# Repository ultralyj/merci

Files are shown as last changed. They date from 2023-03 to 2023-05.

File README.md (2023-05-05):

# MERCI Project

Say Merci!!!

ultralyj的毕设，

looking for the magic of magnet,

say merci to graduate,

------------------------------

项目目前包含：

- [x] 嵌入式代码（基于stm32f4）
- [x] 硬件PCB（包含`F4V3`，`Finger`两款）

  F4V3是30mm试验型磁触觉电子皮肤

  Fringer是安装在AG-145夹爪上的传感器，MCU分体，FPC连接的微型磁触觉电子皮肤

- [x] 3D模型（包含F4V3的模具，压力计外壳，标定用的压头等）

- [x] 传感器网络（目前使用MLP搭建）
- [x] 标定一体化界面（Qt构建，统一管理标定测试台，压力计与电子皮肤，实现电子皮肤标定无人化）
- [x] 电子皮肤上位机（Electrion+React+AntD构建，简明，优美的图形化GUI，包含安装包）
- [x] Comsol磁场仿真模型（对磁化过程进行了简单仿真）

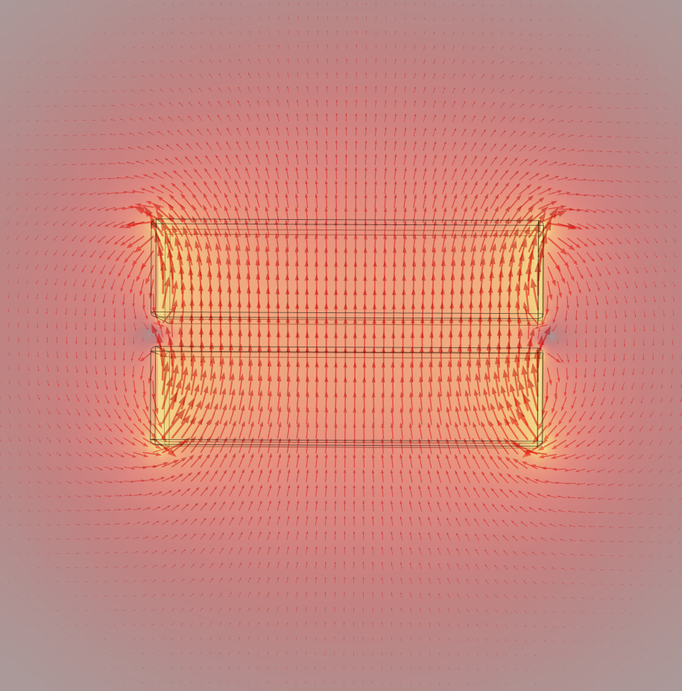
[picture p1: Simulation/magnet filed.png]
magnet filed
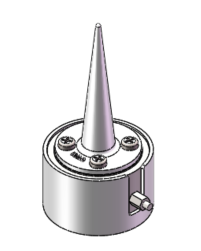
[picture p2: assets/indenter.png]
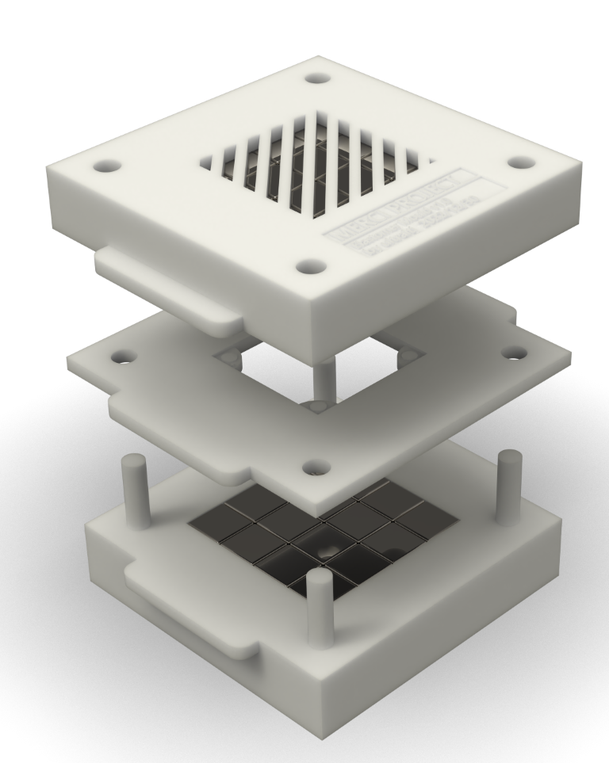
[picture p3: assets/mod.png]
mod
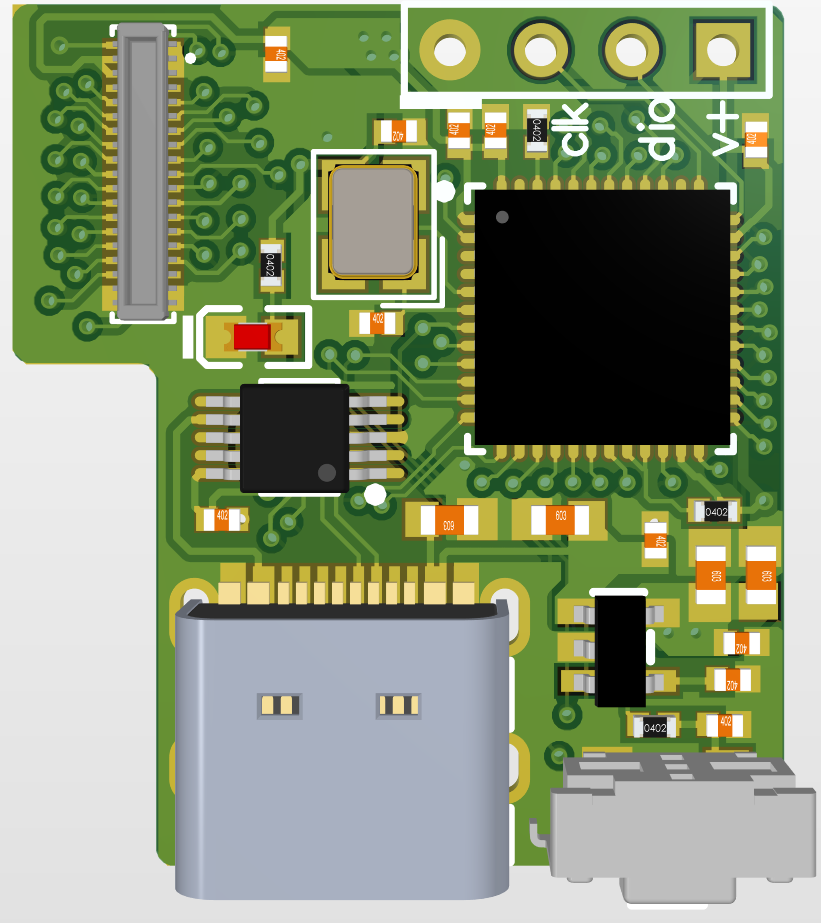
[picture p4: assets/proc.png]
proc
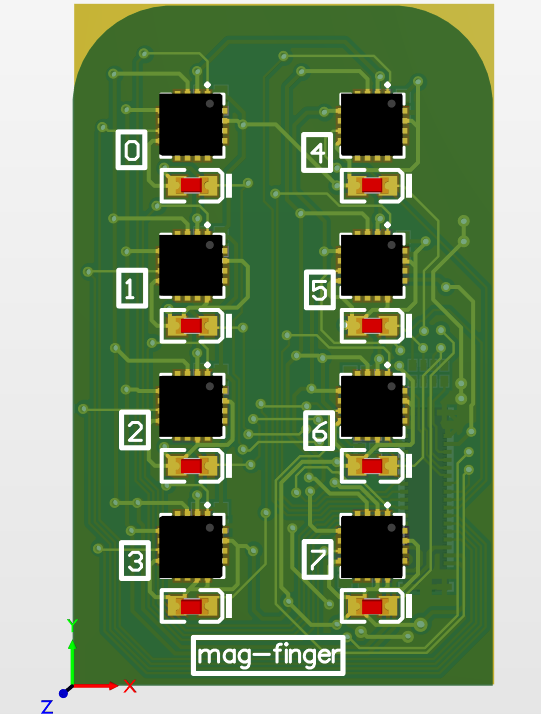
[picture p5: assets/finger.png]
finger
  

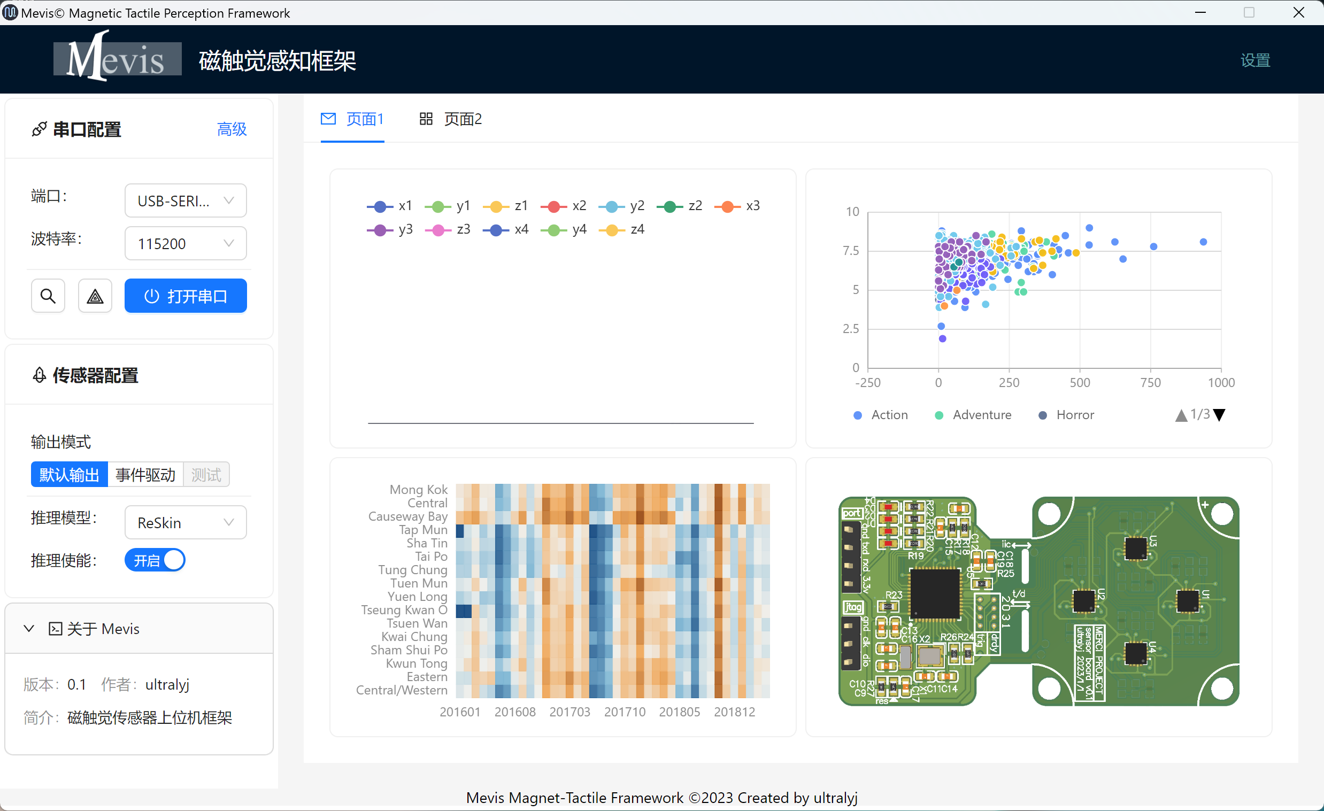
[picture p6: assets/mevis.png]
mevis


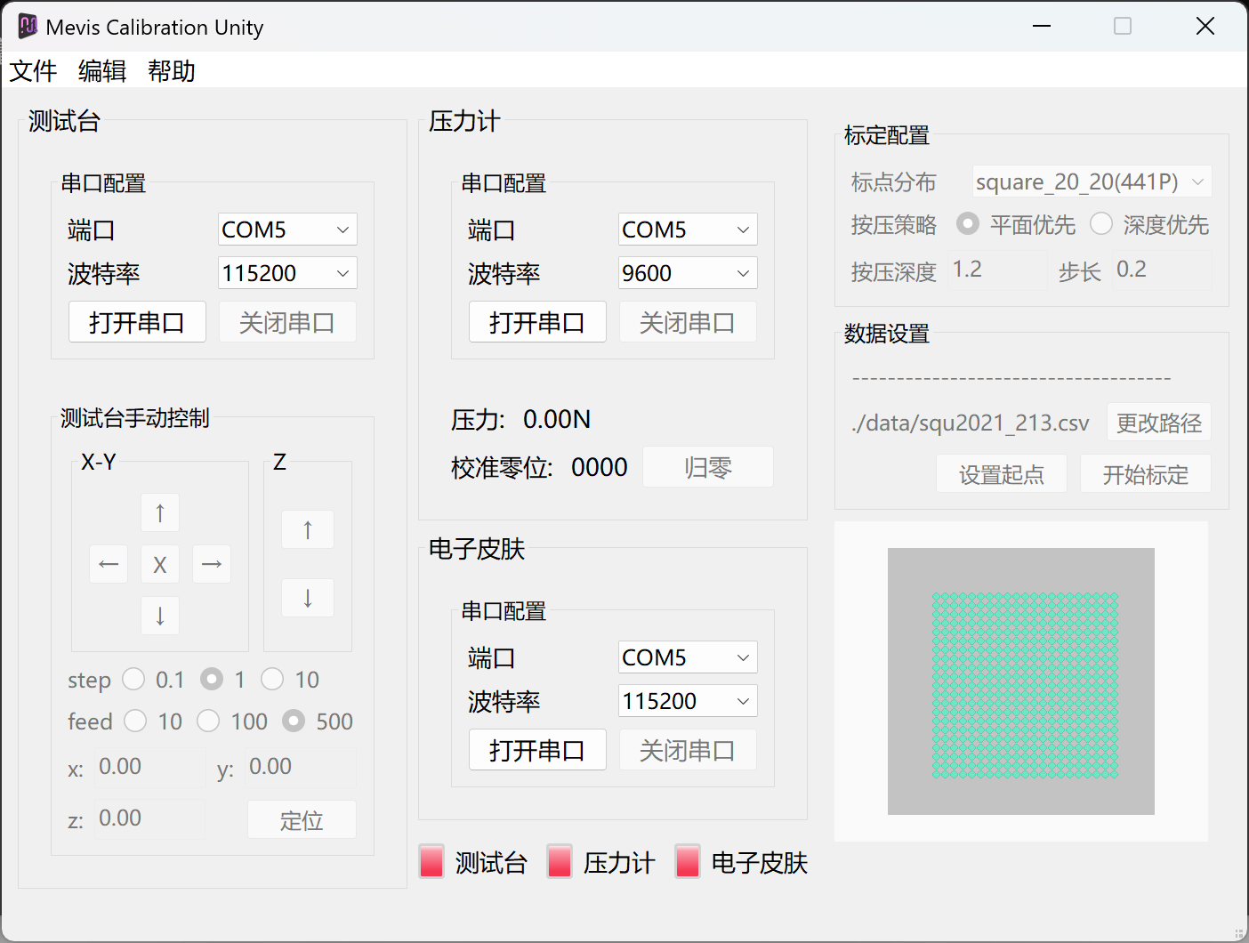
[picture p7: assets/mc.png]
mavis calibration unity


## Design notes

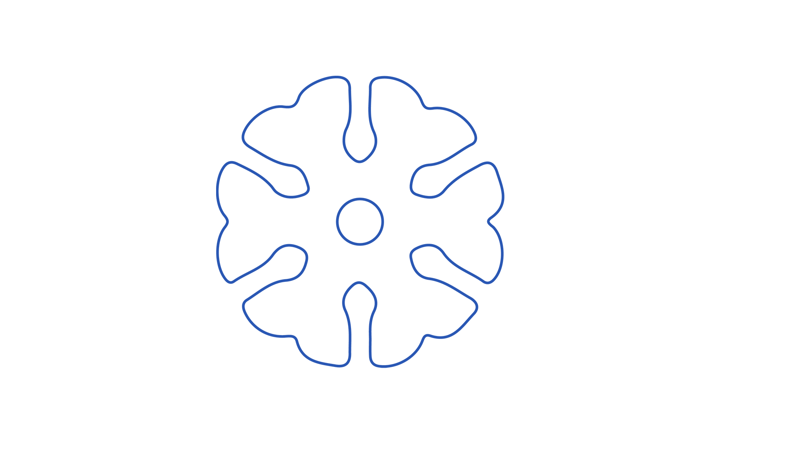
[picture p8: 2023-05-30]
Mevis/src/res/merci_sersorboardv1.0 拷贝.png

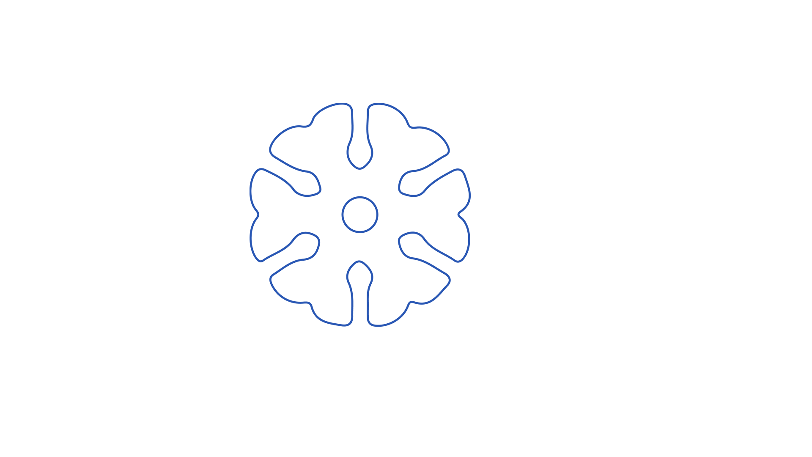
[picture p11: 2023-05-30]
Mevis/src/res/tracking.png

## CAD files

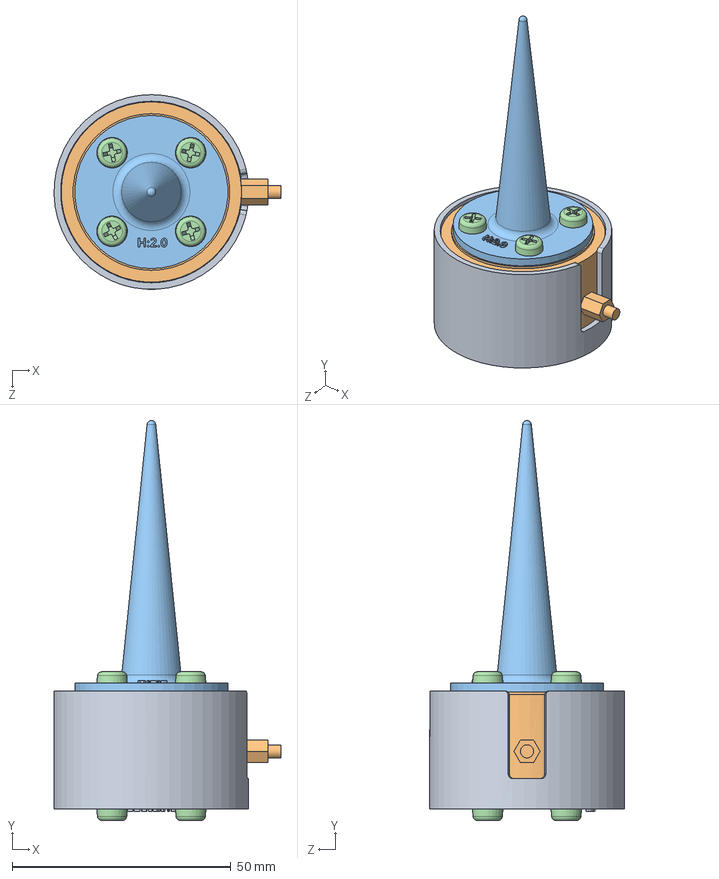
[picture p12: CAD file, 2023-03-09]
Models/press_v2.SLDASM
51.8 x 91.4 x 44.5 mm
press_outer_v2
press_sensor_v2
press_ indenter_v2
cross recessed cheese head screws gb x 9

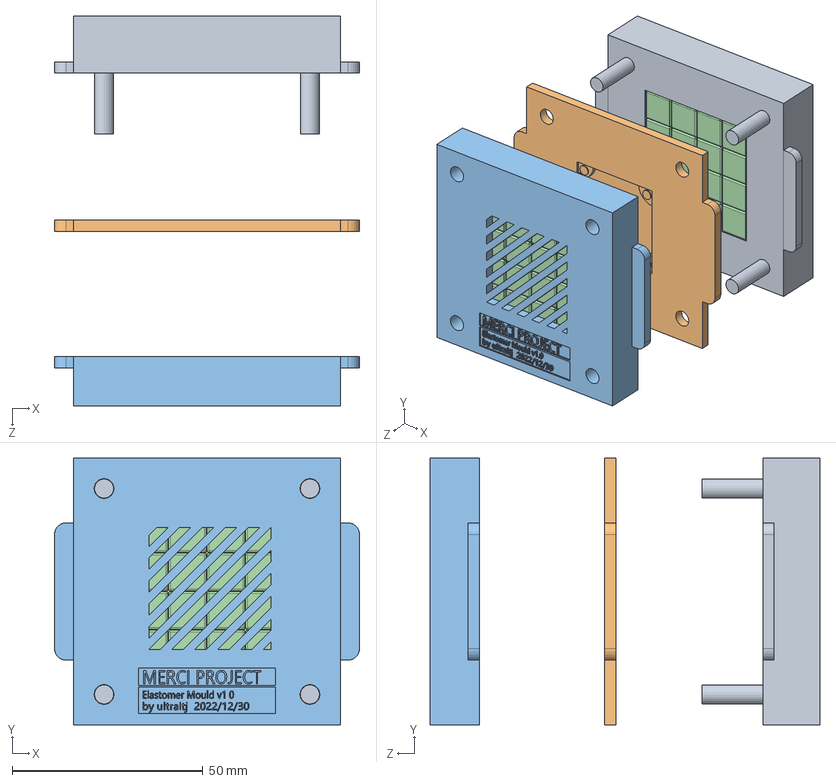
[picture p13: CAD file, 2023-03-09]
Models/mould_v1.SLDASM
80.0 x 70.0 x 102.3 mm
merci_bottom
merci_middle
merci_top
magcube_10mm x 32

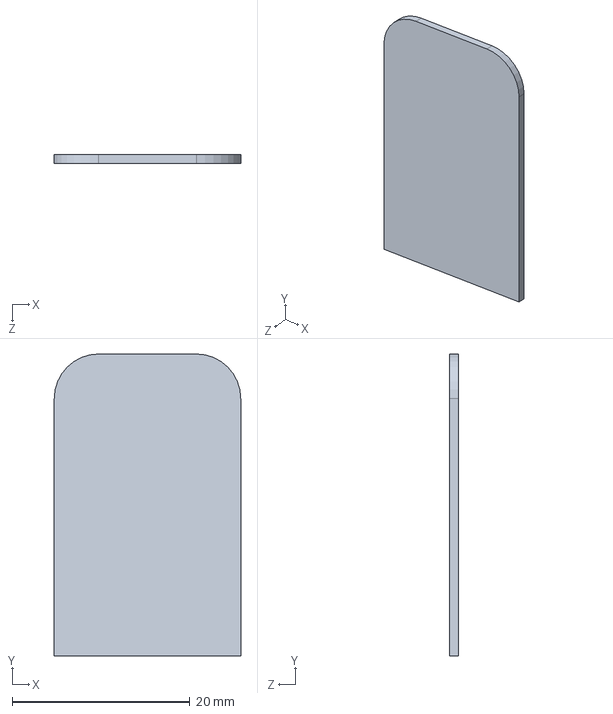
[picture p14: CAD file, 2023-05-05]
Models/finger_border.SLDPRT
21.0 x 34.0 x 1.00 mm

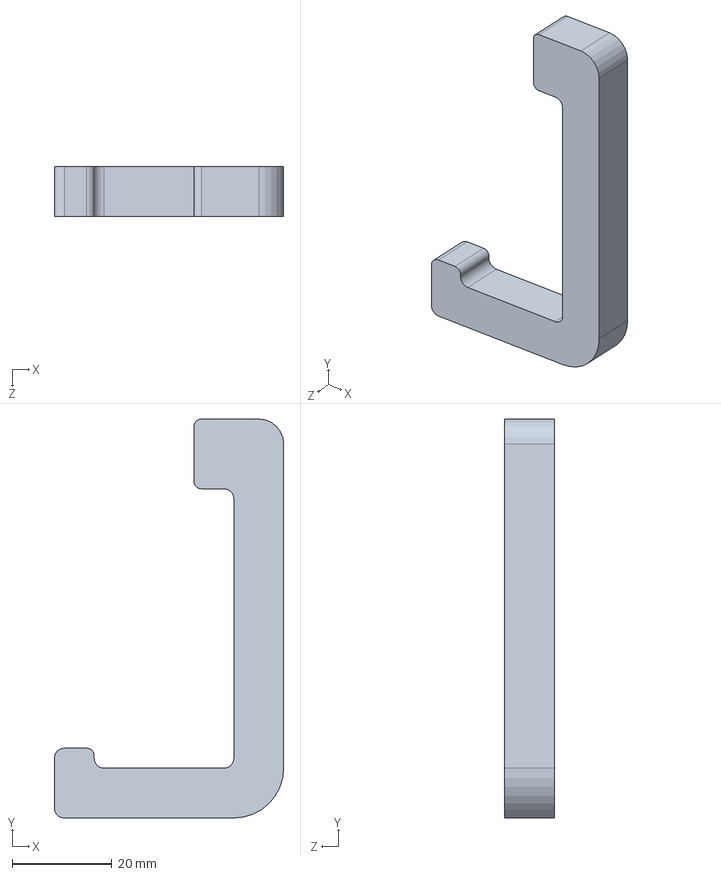
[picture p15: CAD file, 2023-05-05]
Models/fpc.SLDPRT
46.0 x 80.0 x 10.0 mm

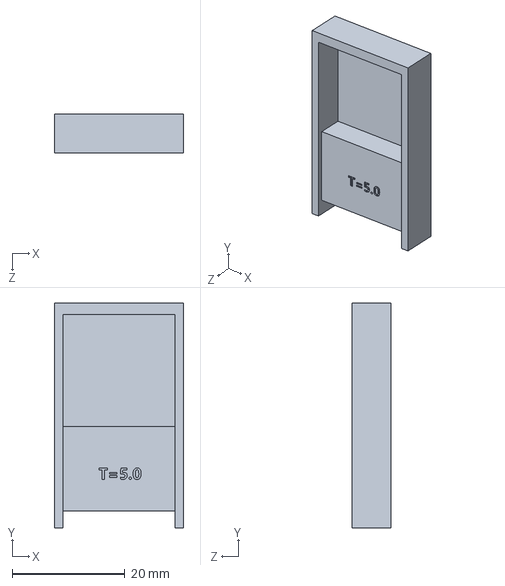
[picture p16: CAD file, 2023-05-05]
Models/T50.SLDPRT
23.0 x 40.0 x 7.00 mm

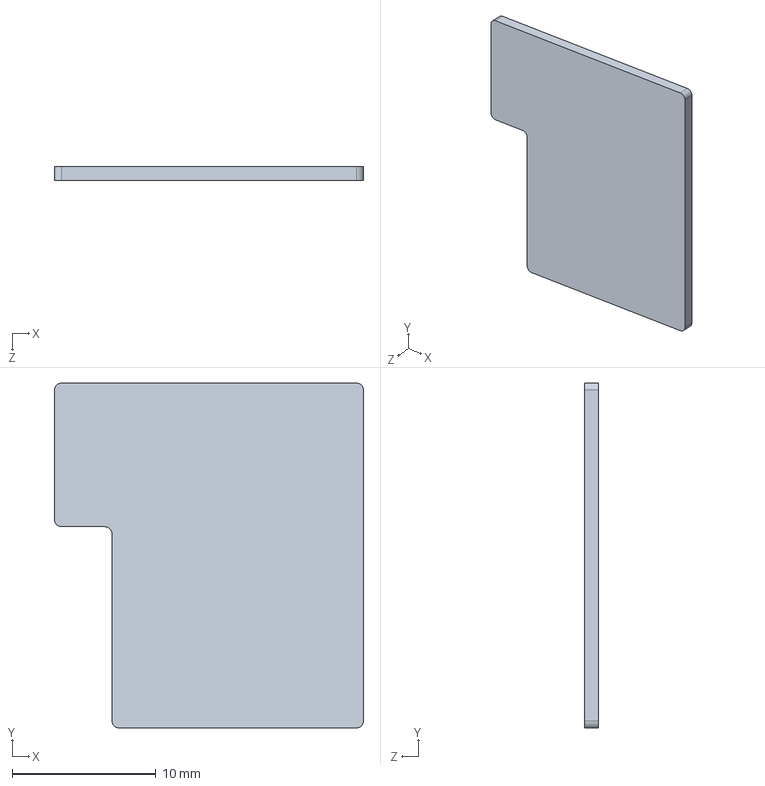
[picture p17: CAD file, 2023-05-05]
Models/proc_border.SLDPRT
21.5 x 24.0 x 1.00 mm

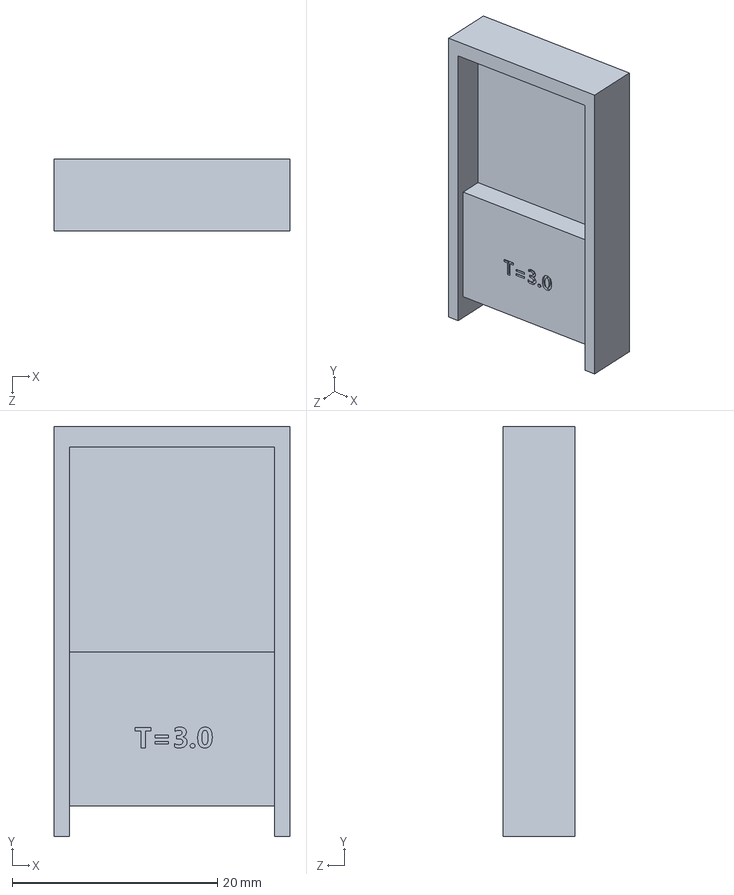
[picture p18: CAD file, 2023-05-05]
Models/T30.SLDPRT
23.0 x 40.0 x 7.00 mm

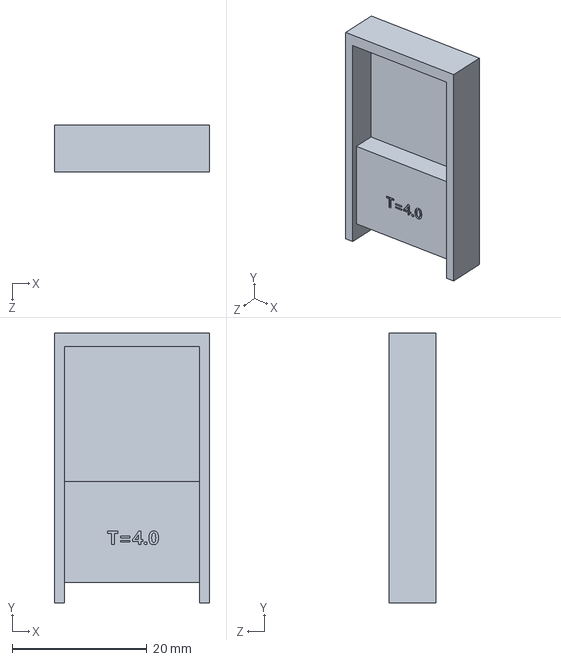
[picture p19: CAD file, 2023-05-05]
Models/T40.SLDPRT
23.0 x 40.0 x 7.00 mm

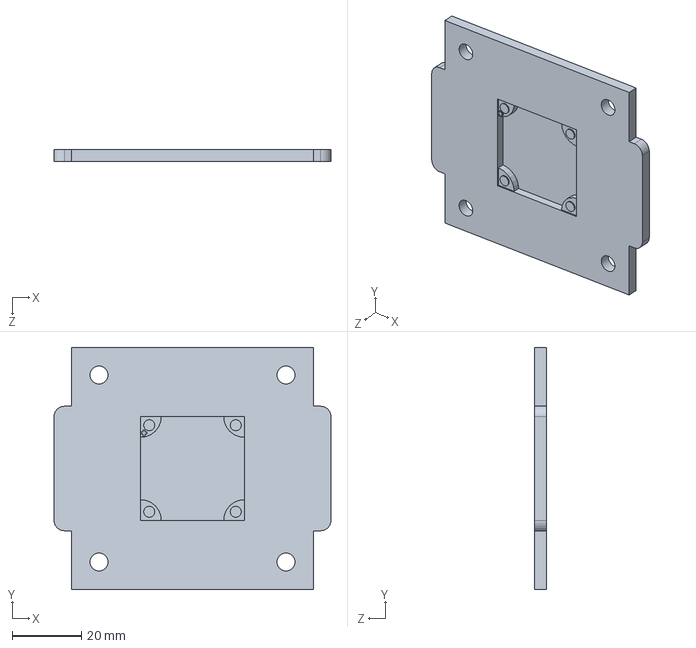
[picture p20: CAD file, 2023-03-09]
Models/merci_middle_2.6.SLDPRT
80.0 x 70.0 x 3.40 mm

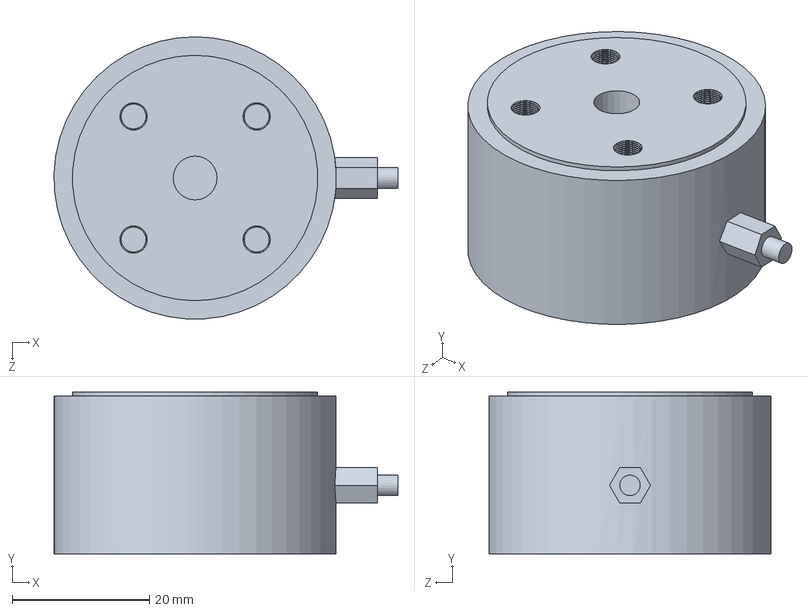
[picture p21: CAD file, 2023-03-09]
Models/press_sensor_v2.SLDPRT
50.2 x 23.6 x 41.2 mm

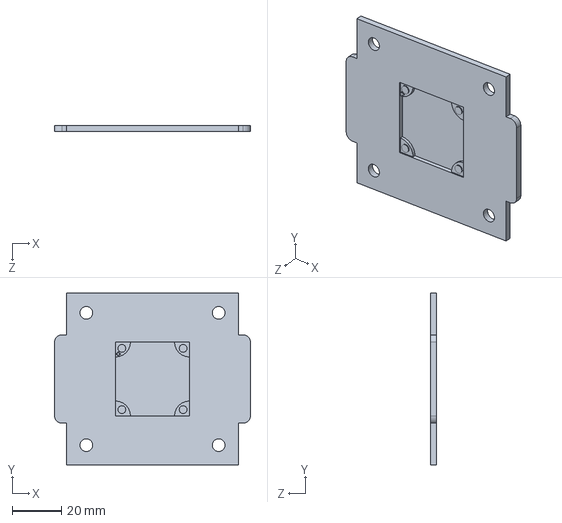
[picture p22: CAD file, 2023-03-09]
Models/merci_middle_1.7.SLDPRT
80.0 x 70.0 x 2.50 mm

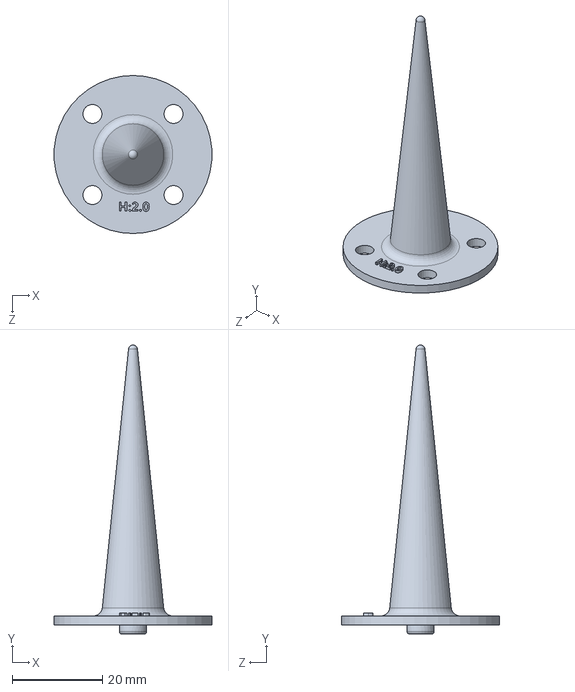
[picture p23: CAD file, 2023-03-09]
Models/press_ indenter_v2.SLDPRT
34.9 x 64.0 x 35.0 mm

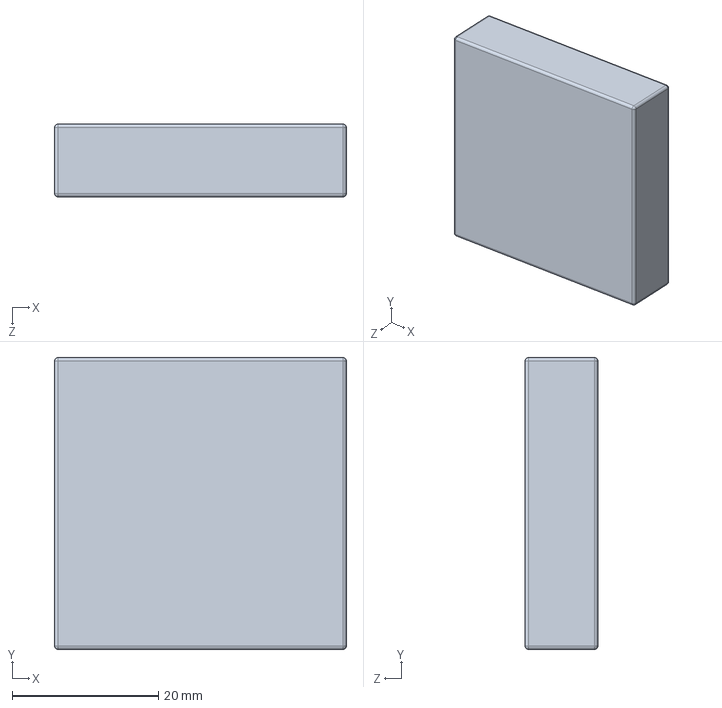
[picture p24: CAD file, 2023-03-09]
Models/magcube_40mm.SLDPRT
40.0 x 40.0 x 10.0 mm

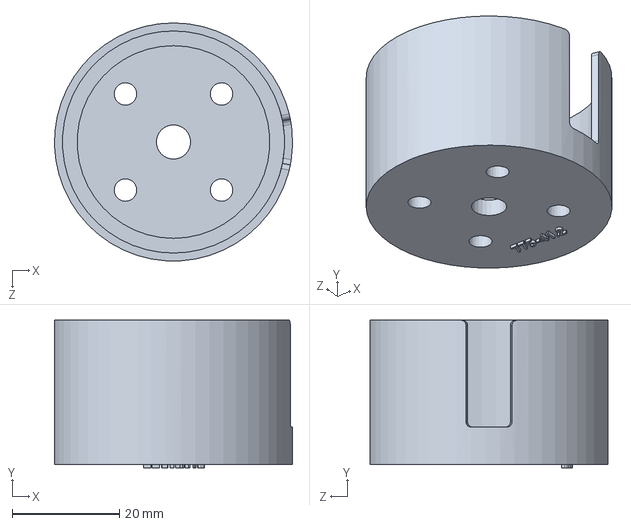
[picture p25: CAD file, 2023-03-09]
Models/press_outer_v2.SLDPRT
44.5 x 27.6 x 44.5 mm

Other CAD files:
Models/press_ indenter.SLDPRT
Models/merci_middle_1.4.SLDPRT
Models/merci_top.SLDPRT
Models/magcube_10mm.SLDPRT
Models/merci_bottom.SLDPRT
Models/merci_middle.SLDPRT
Models/merci_middle_2.3.SLDPRT
Models/press_outer.SLDPRT
Models/press_sensor.SLDPRT
Models/press_v1.SLDASM

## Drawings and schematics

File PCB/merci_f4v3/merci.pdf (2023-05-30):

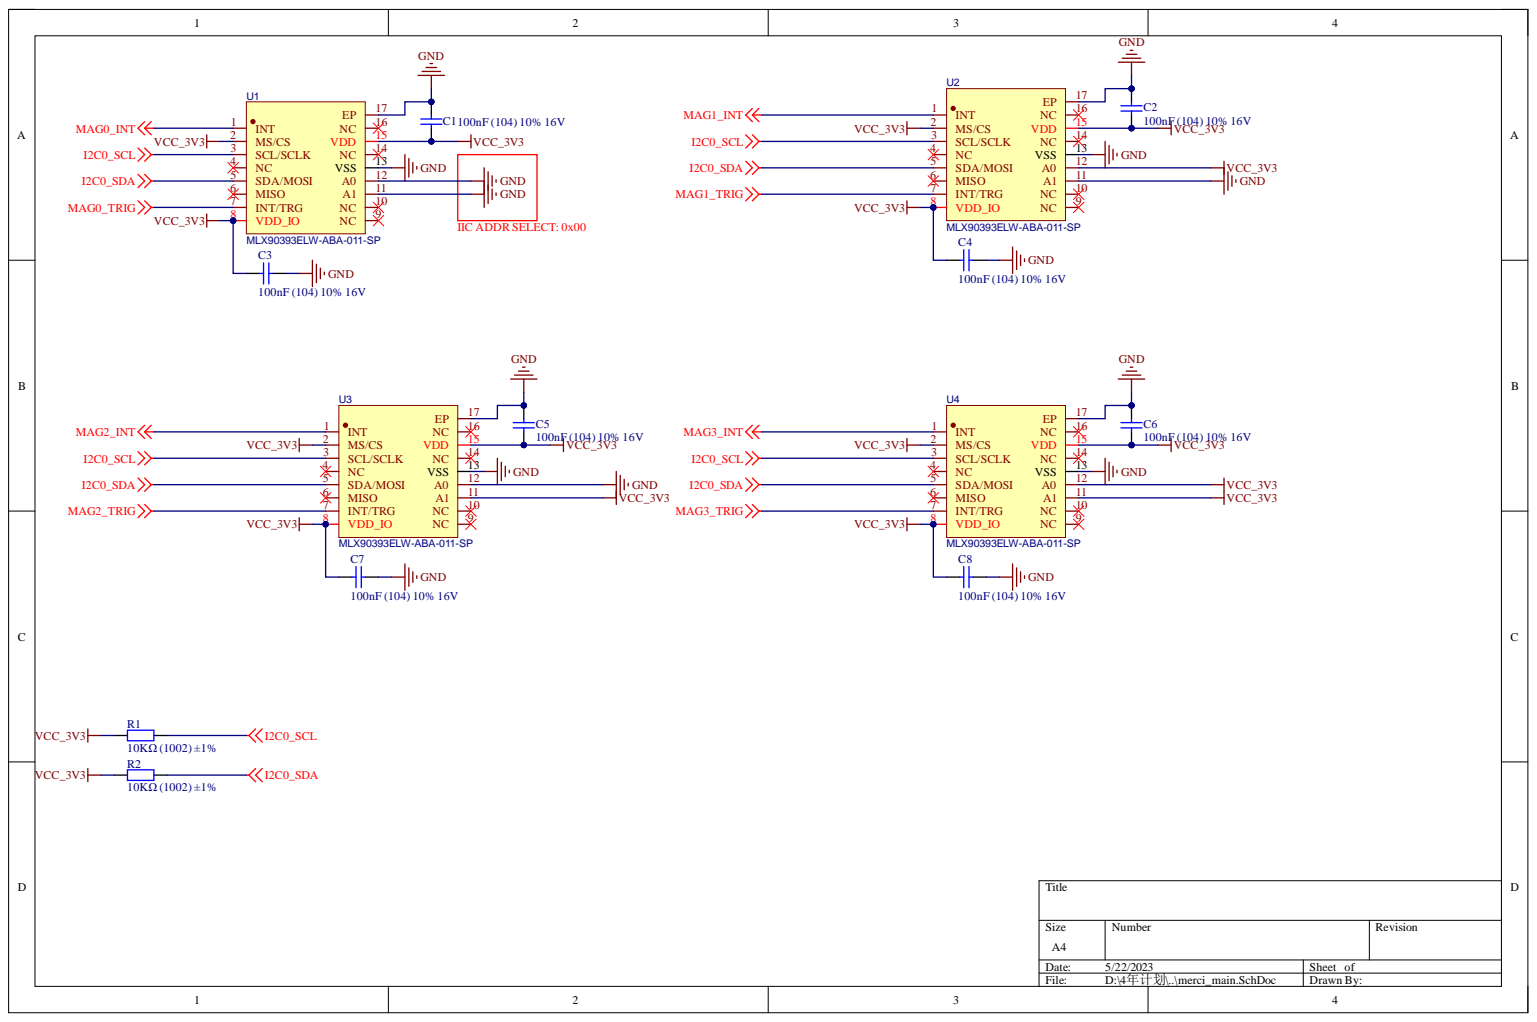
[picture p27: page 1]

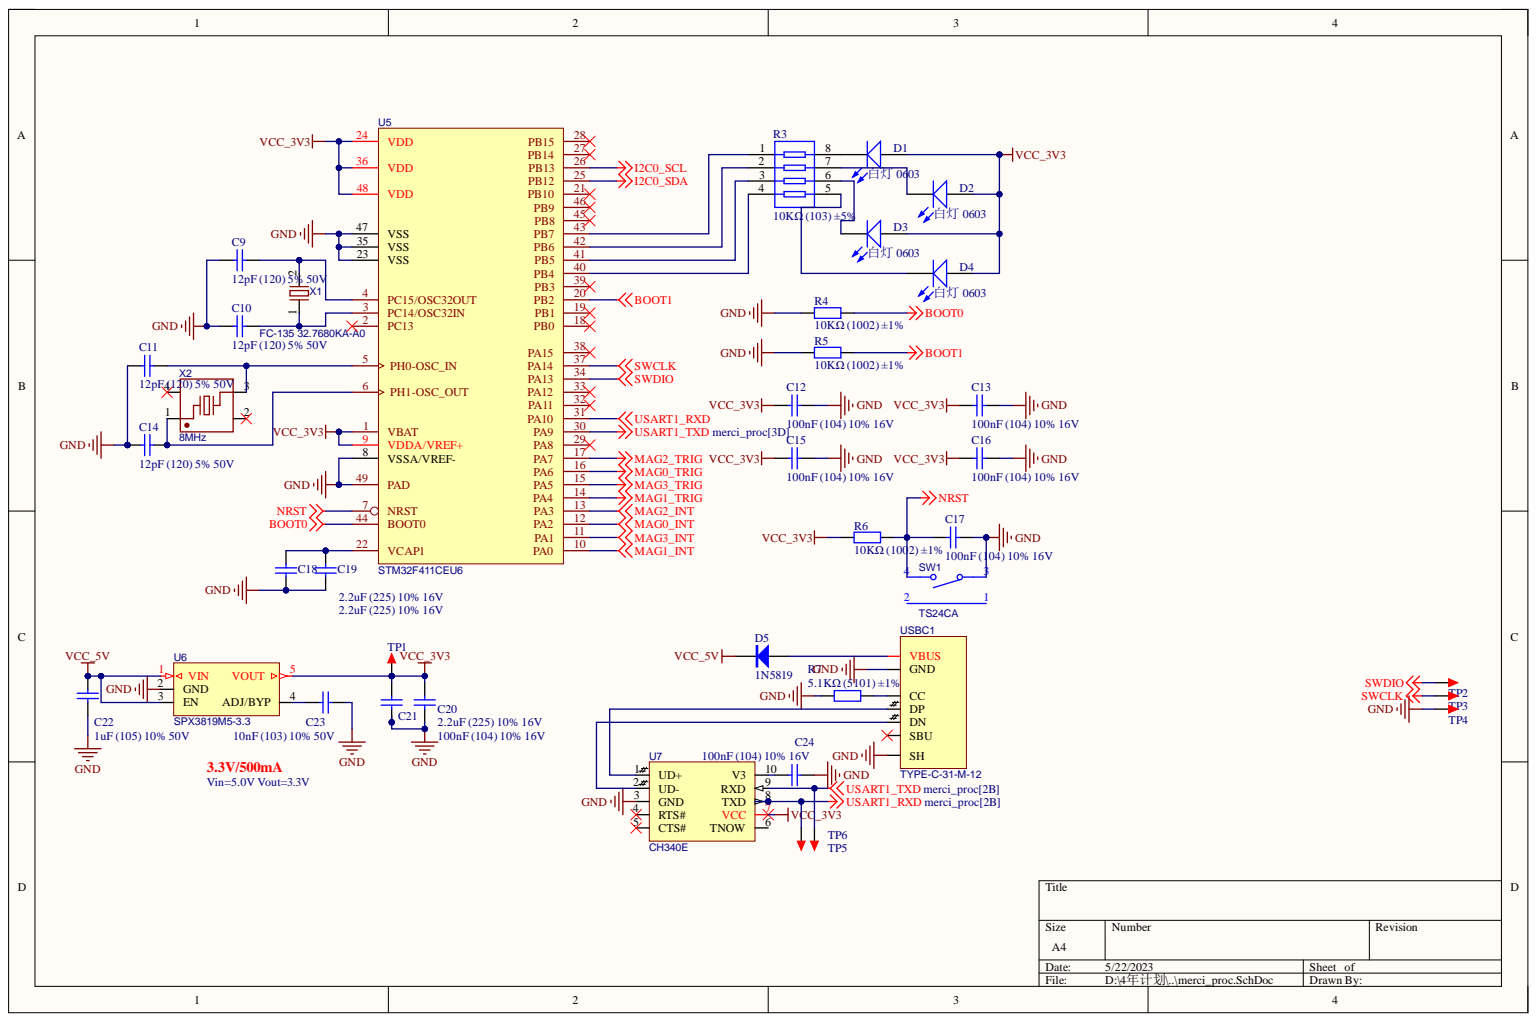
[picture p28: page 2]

46 PB10 21 PB12 25 PB13 26 PB14 27 PB15 28 5 PB9 | I2C0 _SCL | 1234 | R3 10K

3 6
4 8 | 白灯 0 6

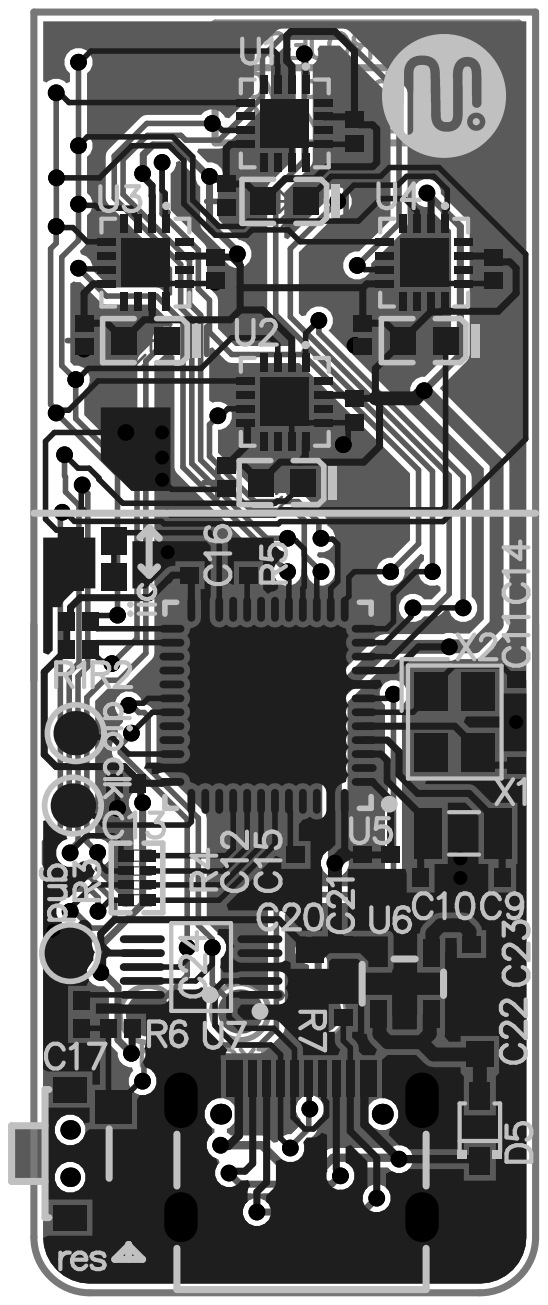
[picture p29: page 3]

Comment | Description | Designator | Footprint | LibRef | Quantity
100nF (104) 10% 16V | 贴片电容 | C1, C2, C3, C4, C5, C6, C7, C8, C12, C13, C15, C16, C17, C21, C24 | LC-0402_C_NOSILK | 0402 100nF (104) 10% 16V | 15
12pF (120) 5% 50V | 贴片电容 | C9, C10, C11, C14 | LC-0402_C_NOSILK | 0402 12pF (120) 5% 50V | 4
2.2uF (225) 10% 16V | 贴片电容 | C18, C19, C20 | LC-0603_C_NOSILK | 0603 2.2uF (225) 10% 16V | 3
1uF (105) 10% 50V | 贴片电容 | C22 | LC-0603_C_NOSILK | 0603 1uF (105) 10% 50V | 1
10nF (103) 10% 50V | 贴片电容 | C23 | LC-0402_C_NOSILK | 0402 10nF (103) 10% 50V | 1
白灯 0603 | 发光二极管 | D1, D2, D3, D4 | LC-0603_LED_S1 | 0603 白灯 | 4
1N5819 | 肖特基二极管 | D5 | SOD-323_L1.8-W1.3-LS2.5-RD | 1N5819 | 1
10KΩ (1002) ±1% | 贴片电阻 | R1, R2, R4, R5, R6 | LC-0402_R_NOSILK | 0402 10KΩ (1002) 1% | 5
10KΩ (103) ±5% | 贴片排阻 | R3 | LC-0402_Rx4 | 0402*4 10KΩ (103) 5% | 1
5.1KΩ (5101) ±1% | 贴片电阻 | R7 | LC-0402_R_NOSILK | 0402 5.1KΩ (5101) 1% | 1
TS24CA | 按键 | SW1 | SW-SMD_TS24CA | TS24CA | 1
TEST | 测试点 | TP1, TP2, TP3, TP4, TP5, TP6 | TEST 1.6 | TEST | 6
MLX90393ELW-ABA-011-SP | | U1, U2, U3, U4 | QFN-16_L3.0-W3.0-P0.50-TR-EP1.7 | MLX90393ELW-ABA-011-SP | 4
STM32F411CEU6 | | U5 | UFQFPN-48_L7.0-W7.0-P0.50-BL-EP -duplicate | STM32F411CEU6 | 1
SPX3819M5-3.3 | Vin=16V Vout=3.3V 500mA LDO | U6 | SOT-23-5_L2.9-W1.6-P0.95-LS2.8-BL SPX3819M5-3.3 | | 1
CH340E | ttl-usb芯片 | U7 | MSOP-10_L3.0-W3.0-P0.50-LS5.0-BL CH340E | | 1
TYPE-C-31-M-12 | 贴片type-c母座 | USBC1 | USB-C_SMD-TYPE-C-31-M-12 | TYPE-C-31-M-12 | 1
FC-135 32.7680KA-A0 | | X1 | CRYSTAL-SMD_L3.2-W1.5-FC-135R32.7680KF-A3 | FC-135 32.7680KA-A0 | 1
8MHz | | X2 | CRYSTAL-SMD_4P-L3.2-W2.5-BL | 8MHz | 1

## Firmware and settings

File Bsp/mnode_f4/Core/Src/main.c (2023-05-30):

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
/* Includes ------------------------------------------------------------------*/
#include "main.h"
#include "crc.h"
#include "usart.h"
#include "gpio.h"

/* USER CODE BEGIN Includes */
#include "mlx90393.h"
#include "tickus.h"
#include "ai_app.h"
#include <stdio.h>
#include <math.h>
/* USER CODE END Includes */

/* USER CODE BEGIN PTD */
typedef struct{
    uint8_t header[4];
    float_t flux[12];
    float_t crc;
    uint32_t time;
    float_t x;
    float_t y;
    float_t F;
    uint32_t status;
}frameStructure;
/* USER CODE END PTD */

/* USER CODE BEGIN PD */
#define AI_EABLE 1
#define AI_DEBUG 0
#define OUTPUT_FORMAT_ASCII 0
/* USER CODE END PD */


/* USER CODE BEGIN PV */

/**
 * @brief configuration data of 4 mlx90393 chips, including I2C address(A0|A1), drdy PIN and trig PIN
 *
 */
const Mlx90393ConfTypeDef mag_conf[4] =
{
    [0] = {
        .A0 = 0,
        .A1 = 0,
        .drdy_port = GPIOA,
        .drdy_pin = GPIO_PIN_2,
        .trig_port = GPIOA,
        .trig_pin = GPIO_PIN_6},
    [1] = {
        .A0 = 1,
        .A1 = 0,
        .drdy_port = GPIOA,
        .drdy_pin = GPIO_PIN_0,
        .trig_port = GPIOA,
        .trig_pin = GPIO_PIN_4},
    [2] = {
        .A0 = 0,
        .A1 = 1,
        .drdy_port = GPIOA,
        .drdy_pin = GPIO_PIN_3,
        .trig_port = GPIOA,
        .trig_pin = GPIO_PIN_7},
    [3] = {
        .A0 = 1,
        .A1 = 1,
        .drdy_port = GPIOA,
        .drdy_pin = GPIO_PIN_1,
        .trig_port = GPIOA,
        .trig_pin = GPIO_PIN_5}
};

/**
 * @brief temperature and magnitude data after converting from raw frame
 *
 */
static float dataConv[4][4];
static float dataBias[4][4];

/**
 * @brief handler of 4 mlx90393 chips
 */
static Mlx90393TypeDef hmag[4];

/* USER CODE END PV */

void SystemClock_Config(void);
/* USER CODE BEGIN PFP */
void get_dataBias(float dataBias[4][4]);
/* USER CODE END PFP */

/* USER CODE BEGIN 0 */


/**
  * @brief  The application entry point.
  * @retval int
  */
int main(void)
{
  /* MCU Configuration--------------------------------------------------------*/

  /* Reset of all peripherals, Initializes the Flash interface and the Systick. */
  HAL_Init();

  /* Configure the system clock */
  SystemClock_Config();

  /* Initialize all configured peripherals */
  MX_GPIO_Init();
  MX_USART1_UART_Init();
  MX_CRC_Init();
  /* USER CODE BEGIN 2 */
    /* scan I2C devices on the bus(0-127) */
    // I2C_SCAN(); //addr: 14 15 16 17

	#if AI_ENABLE
	ai_Init();
	
	/* brief information */
    printf("\r\nmlx90393_f4_v1.0 with AI on board\r\n");
    printf("auther:ultrlyj, build:%s,%s\r\n", __DATE__, __TIME__);
	#else
	printf("\r\nmlx90393_f4_v1.0 without AI on board\r\n");
    printf("auther:ultrlyj, build:%s,%s\r\n", __DATE__, __TIME__);
	#endif
    
    /* initialize the I2C bus and 4 mlx90393 chips */
    I2C_Init();
	
    for (uint8_t i = 0; i < 4; i++)
		if(!Peri_Mlx90393_Init(&hmag[i], &mag_conf[i]))
		{
			printf("ok ");
		}
        else
		{
			printf("failed");
		}
	printf("\r\n");

    static frameStructure frame;
    frame.header[0] = '$';
    frame.header[1] = 'M';
    frame.header[2] = 'A';
    frame.header[3] = 'G';
	
  /* USER CODE END 2 */

  /* Infinite loop */
  /* USER CODE BEGIN WHILE */
#if AI_EABLE
	#if AI_DEBUG
    extern const float test_in[100][12];
    extern const float y_pc[100][2];
	float test_out[2]={0,0};
	for(int i=0;i<100;i++)
	{
		uint32_t time_start = getCurrentMicros();
		ai_Run((float*)(test_in[i]),test_out);
		uint32_t time_end = getCurrentMicros();
		float error = sqrt((y_pc[i][0]-test_out[0])*(y_pc[i][0]-test_out[0]) + (y_pc[i][1]-test_out[1])*(y_pc[i][1]-test_out[1]));
		printf("%f,%f,%f,%d\r\n",test_out[0],test_out[1],error,time_end-time_start);
       HAL_GPIO_TogglePin(LED0_GPIO_Port, LED0_Pin | LED1_Pin | LED2_Pin | LED3_Pin);
	}
	#endif	
#endif
	/* get flux density bias */
	get_dataBias(dataBias);

    while (1)
    {
        uint32_t time_tick = HAL_GetTick();
        /* send tirg signal at the same time*/
        for (uint8_t i = 0; i < 4; i++)
            Peri_Mlx90393_Trig(&hmag[i]);
    
        /* wait until 4 sensor finish their measurement */
        for (uint8_t i = 0; i < 4; i++)
        {
            if (!Peri_Mlx90393_waitReady(&hmag[i]))
                Peri_Mlx90393_readData(&hmag[i], dataConv[i]);
        }
        
        /* get crc check value */
		float crc = 0.0f;
        for (uint8_t i = 0; i < 4; i++)
        {
            for (uint8_t j = 1; j < 4; j++)
            {
				float x = dataConv[i][j]-dataBias[i][j];
				frame.flux[i*3+j-1] = x;
				crc+=x;			
            }
        }
        /* CNN model predict */
		#if AI_EABLE
        float predict[2];
        ai_Run((float*)(frame.flux), predict);
		frame.x = predict[0];
        frame.y = predict[1];
		#endif
        frame.crc = crc;
        frame.time = time_tick;
        
        frame.status = 0;

        #if OUTPUT_FORMAT_ASCII
        /* support IPC: mevis, serialplot, mevis calibrate unity */
        for (uint8_t i = 0; i < 12; i++)
            printf("%.2f,",frame.flux[i]);
        printf("%.2f\n", frame.crc);
        #else
        HAL_UART_Transmit(&huart1, (uint8_t *)&frame, 76, 0xffff);
        while (__HAL_UART_GET_FLAG(&huart1, UART_FLAG_TC) == RESET);
        #endif
		HAL_GPIO_TogglePin(LED0_GPIO_Port, LED0_Pin | LED1_Pin | LED2_Pin | LED3_Pin);
    /* USER CODE END WHILE */

    /* USER CODE BEGIN 3 */
    }
  /* USER CODE END 3 */
}

void get_dataBias(float dataBias[4][4])
{
	const uint16_t times = 200;
	for (uint8_t i = 0; i < 4; i++)
		for (uint8_t j = 0; j < 4; j++)
		dataBias[i][j] = 0.0f;
	for (uint16_t t = 0; t < times; t++)
	{
		/* send tirg signal at the same time*/
		for (uint8_t i = 0; i < 4; i++)
			Peri_Mlx90393_Trig(&hmag[i]);

		/* wait until 4 sensor finish their measurement */
		for (uint8_t i = 0; i < 4; i++)
		{
			if (!Peri_Mlx90393_waitReady(&hmag[i]))
				Peri_Mlx90393_readData(&hmag[i], dataConv[i]);
		}
		
		/* output data(ascii data only for test) */
		float crc = 0.0f;
		for (uint8_t i = 0; i < 4; i++)
		{
			for (uint8_t j = 1; j < 4; j++)
			{
				float x = dataConv[i][j];
				x=(int)100*x+0.5;
				x=x/100;
				dataBias[i][j] += x;			
			}
		}
	}
	for (uint8_t i = 0; i < 4; i++)
		for (uint8_t j = 0; j < 4; j++)
		dataBias[i][j] /= times;
	
}
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


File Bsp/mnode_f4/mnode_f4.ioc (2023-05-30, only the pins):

Mcu.UserName=STM32F411CEUx
PA10.Signal=USART1_RX
PA13.Signal=SYS_JTMS-SWDIO
PA14.Signal=SYS_JTCK-SWCLK
PA9.Signal=USART1_TX
PB4.GPIO_Label=LED0
PB4.Signal=GPIO_Output
PB5.GPIO_Label=LED1
PB5.Signal=GPIO_Output
PB6.GPIO_Label=LED2
PB6.Signal=GPIO_Output
PB7.GPIO_Label=LED3
PB7.Signal=GPIO_Output
PC14-OSC32_IN.Signal=RCC_OSC32_IN
PC15-OSC32_OUT.Signal=RCC_OSC32_OUT

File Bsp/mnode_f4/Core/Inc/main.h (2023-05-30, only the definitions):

#define LED0_Pin GPIO_PIN_4
#define LED0_GPIO_Port GPIOB
#define LED1_Pin GPIO_PIN_5
#define LED1_GPIO_Port GPIOB
#define LED2_Pin GPIO_PIN_6
#define LED2_GPIO_Port GPIOB
#define LED3_Pin GPIO_PIN_7
#define LED3_GPIO_Port GPIOB

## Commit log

2023-03-09 整合第一版
    [Cap.SchLib, CrystalOscillator.SchLib, Diode.SchLib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]
2023-03-12 update Calibration
    [magcube_10mm.SLDPRT, magcube_40mm.SLDPRT, merci_bottom.SLDPRT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]
2023-05-05 add net models
    [T30.SLDPRT, T40.SLDPRT, T50.SLDPRT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]
2023-05-30 5.30 update
    [merci.PcbLib, merci.PrjPcb, merci.SchLib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]

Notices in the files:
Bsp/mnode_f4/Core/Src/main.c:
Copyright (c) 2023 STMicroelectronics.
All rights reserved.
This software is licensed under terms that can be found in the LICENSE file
